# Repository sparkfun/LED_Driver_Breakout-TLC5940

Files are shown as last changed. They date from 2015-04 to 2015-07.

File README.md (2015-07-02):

SparkFun LED Driver Breakout -TLC5940
========================================

SparkFun LED Driver Breakout -TLC5940

[*SparkFun LED Driver Breakout -TLC5940(BOB-10616)*](https://www.sparkfun.com/products/10616)

 The TLC5940 is a 16 channel PWM unit with 12 bit duty cycle control (0-4095), 6 bit current limit control (0-63), and a daisy chainable serial interface. 
 This breakout board is a good way to take full advantage of this useful IC. 
 All 16 PWM channels are broken out to standard 0.1" headers, which run alongside convenient voltage and ground rails.

Repository Contents
-------------------

* **/Firmware** - Example code. 
* **/Hardware** - Eagle design files (.brd, .sch)
* **/Libraries** - Libraries for use with the TLC5940.
* **/Production** - Production panel files (.brd)

Documentation
--------------
* **[Library](https://github.com/sparkfun/SparkFun_TLC5940_Arduino_Library)** - Arduino Library for the TLC5940.
* **[SparkFun Fritzing repo](https://github.com/sparkfun/Fritzing_Parts)** - Fritzing diagrams for SparkFun products.
* **[SparkFun 3D Model repo](https://github.com/sparkfun/3D_Models)** - 3D models of SparkFun products. 

Version History
---------------

* [v1.3](https://github.com/sparkfun/LED_Driver_Breakout-TLC5940/tree/V_H1.3_L1.0.1) - Hardware version 1.3. Currently live. 
* [v1.2](https://github.com/sparkfun/LED_Driver_Breakout-TLC5940/tree/V_H.1_L1.0.1) - Hardware version 1.2

License Information
-------------------
This product is _**open source**_! 

The **hardware** is released under [Creative Commons ShareAlike 4.0 International](https://creativecommons.org/licenses/by-sa/4.0/).

Please use, reuse, and modify these files as you see fit. Please maintain attribution to SparkFun Electronics and release anything derivative under the same license.

Distributed as-is; no warranty is given.

- Your friends at SparkFun.

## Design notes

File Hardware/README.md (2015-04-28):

SparkFun <PRODUCT NAME> Design Files
=====================================

The .sch and .brd files hare are Eagle CAD schematic and PCB design files from SparkFun Electronics.
A freeware version of Eagle can be found [here](http://www.cadsoftusa.com/download-eagle/freeware/). 

License
---------
This product is open source! 
The hardware is released under [Creative Commons ShareAlike 4.0 International](https://creativecommons.org/licenses/by-sa/4.0/).

Please use, reuse, and modify these files as you see fit. Please maintain attribution to SparkFun Electronics and release anything derivative under the same license.

Distributed as-is; no warranty is given.

- Your friends at SparkFun.

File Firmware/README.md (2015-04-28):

SparkFun LED Driver Breakout - TLC5940 Firmware
==================================================

* **SparkFunHangingLEDArrayPongDemo* - Arduino Example. Used in this [hookup guide](https://learn.sparkfun.com/tutorials/interactive-hanging-led-array).

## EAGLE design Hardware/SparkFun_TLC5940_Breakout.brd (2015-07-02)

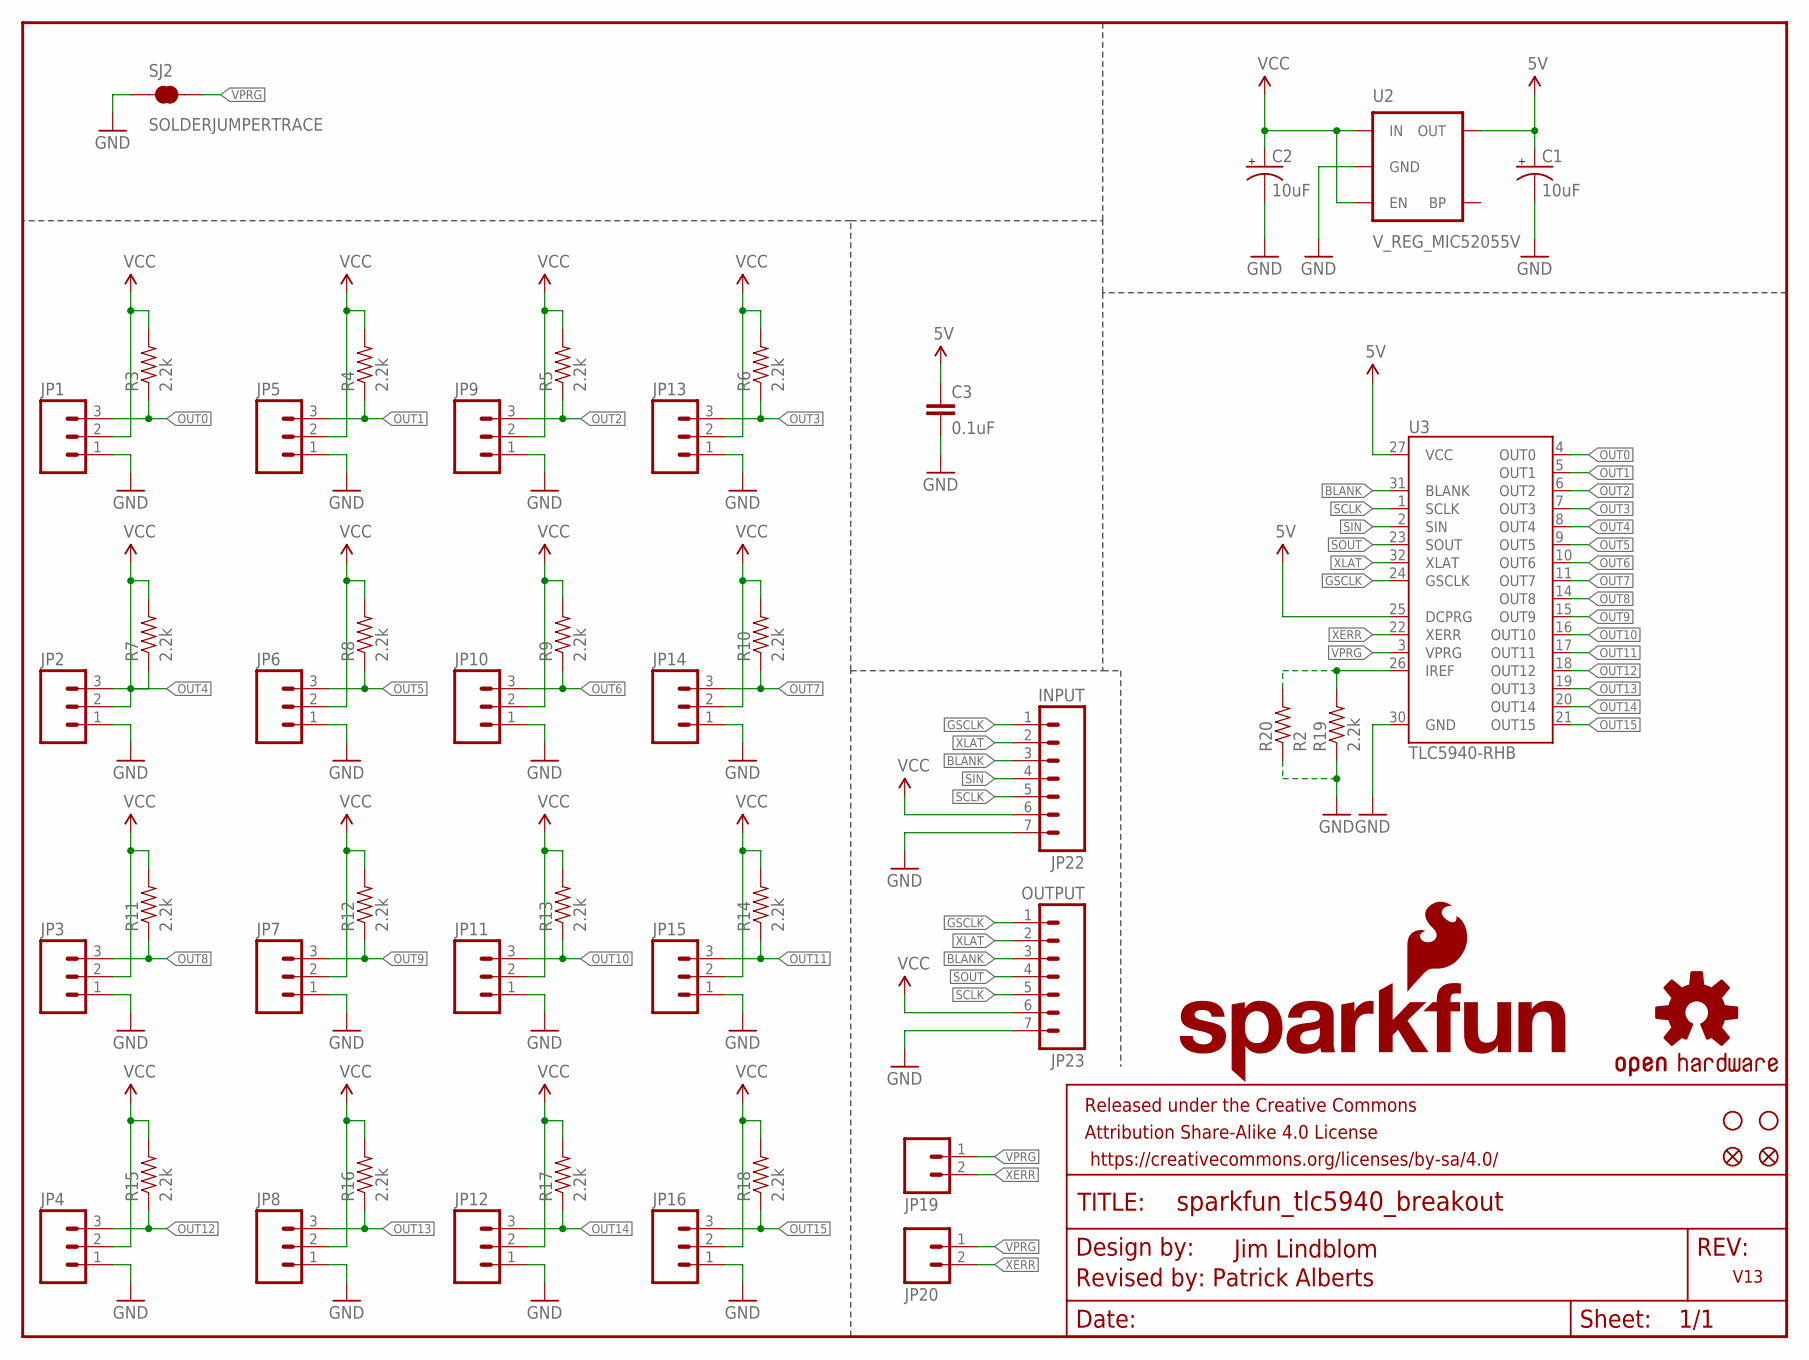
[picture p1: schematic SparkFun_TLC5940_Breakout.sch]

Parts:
C1: 10uF; EIA3216
C2: 10uF; EIA3528
C3: 0.1uF; 0603-CAP
FRAME1: FRAME-LETTER; CREATIVE_COMMONS
JP1, JP2, JP3, JP4, JP5, JP6, JP7, JP8, JP9, JP10, JP11, JP12, JP13, JP14, JP15, JP16: M03PTH; 1X03
JP17, JP18: STAND-OFF
JP19, JP20: M02PTH; 1X02
JP21, JP26: FIDUCIAL1X2; FIDUCIAL-1X2
JP22: INPUT; 1X07
JP23: OUTPUT; 1X07
LOGO1: OSHW-LOGOS; OSHW-LOGO-S
LOGO2: SFE_LOGO_NAME_FLAME.2_INCH; SFE_LOGO_NAME_FLAME_.2
R3, R4, R5, R6, R7, R8, R9, R10, R11, R12, R13, R14, R15, R16, R17, R18, R19: 2.2k; 0603-RES
R20: R2; AXIAL-0.3-KIT
SJ2: SOLDERJUMPERTRACE; SJ_2S-TRACE
U2: V_REG_MIC52055V; SOT23-5
U3: TLC5940-RHB; QFN-32

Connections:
5V: C1.A (+), C3.1, U2.5 (OUT), U3.25 (DCPRG), U3.27 (VCC)
BLANK: JP22.3, JP23.3, U3.31 (BLANK)
GND: C1.C (-), C2.C (-), C3.2, JP1.1, JP2.1, JP3.1, JP4.1, JP5.1, JP6.1, JP7.1, JP8.1, JP9.1, JP10.1, JP11.1, JP12.1, JP13.1, JP14.1, JP15.1, JP16.1, JP22.7, JP23.7, R19.1, R20.P$1 (1), SJ2.1, U2.2 (GND), U3.30 (GND)
GSCLK: JP22.1, JP23.1, U3.24 (GSCLK)
unnamed: R19.2, R20.P$2 (2), U3.26 (IREF)
OUT0: JP1.3, R3.1, U3.4 (OUT0)
OUT1: JP5.3, R4.1, U3.5 (OUT1)
OUT2: JP9.3, R5.1, U3.6 (OUT2)
OUT3: JP13.3, R6.1, U3.7 (OUT3)
OUT4: JP2.3, R7.1, U3.8 (OUT4)
OUT5: JP6.3, R8.1, U3.9 (OUT5)
OUT6: JP10.3, R9.1, U3.10 (OUT6)
OUT7: JP14.3, R10.1, U3.11 (OUT7)
OUT8: JP3.3, R11.1, U3.14 (OUT8)
OUT9: JP7.3, R12.1, U3.15 (OUT9)
OUT10: JP11.3, R13.1, U3.16 (OUT10)
OUT11: JP15.3, R14.1, U3.17 (OUT11)
OUT12: JP4.3, R15.1, U3.18 (OUT12)
OUT13: JP8.3, R16.1, U3.19 (OUT13)
OUT14: JP12.3, R17.1, U3.20 (OUT14)
OUT15: JP16.3, R18.1, U3.21 (OUT15)
SCLK: JP22.5, JP23.5, U3.1 (SCLK)
SIN: JP22.4, U3.2 (SIN)
SOUT: JP23.4, U3.23 (SOUT)
VCC: C2.A (+), JP1.2, JP2.2, JP3.2, JP4.2, JP5.2, JP6.2, JP7.2, JP8.2, JP9.2, JP10.2, JP11.2, JP12.2, JP13.2, JP14.2, JP15.2, JP16.2, JP22.6, JP23.6, R3.2, R4.2, R5.2, R6.2, R7.2, R8.2, R9.2, R10.2, R11.2, R12.2, R13.2, R14.2, R15.2, R16.2, R17.2, R18.2, U2.1 (IN), U2.3 (EN)
VPRG: JP19.1, JP20.1, SJ2.2, U3.3 (VPRG)
XERR: JP19.2, JP20.2, U3.22 (XERR)
XLAT: JP22.2, JP23.2, U3.32 (XLAT)

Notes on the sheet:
V13
Jim Lindblom
Revised by: Patrick Alberts

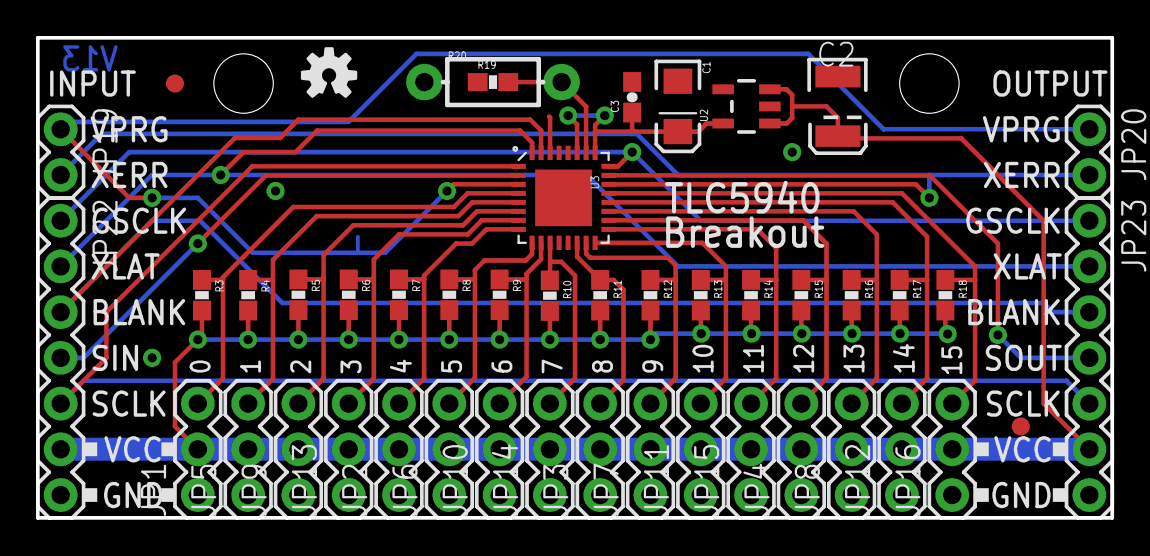
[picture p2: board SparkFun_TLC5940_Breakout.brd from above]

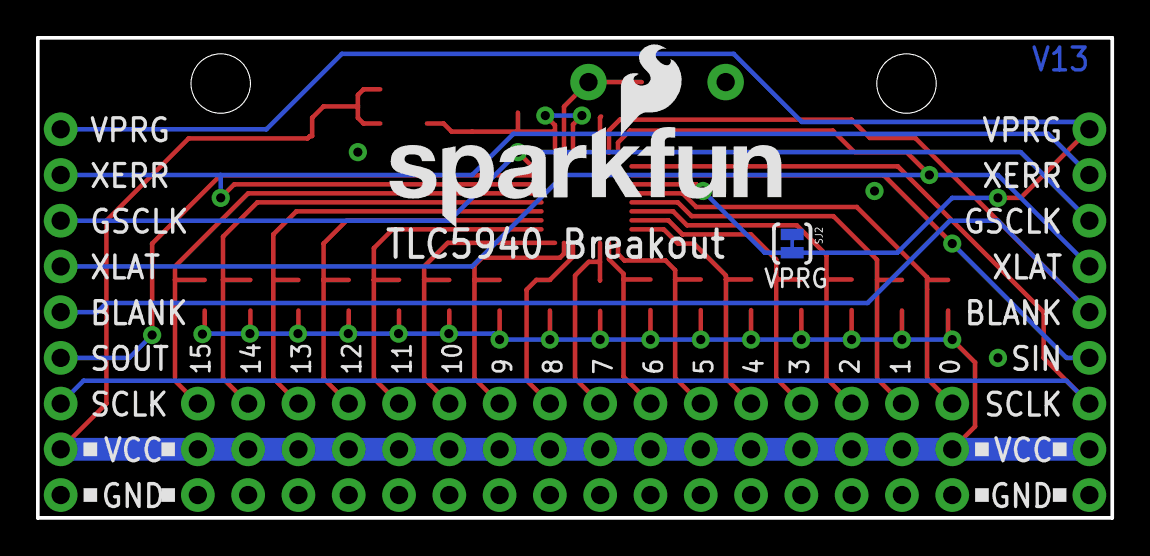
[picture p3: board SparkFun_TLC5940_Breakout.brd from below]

Board: 2 copper layers, 59.7 x 26.7 mm, 51 parts (2 on the bottom side), 28 nets.

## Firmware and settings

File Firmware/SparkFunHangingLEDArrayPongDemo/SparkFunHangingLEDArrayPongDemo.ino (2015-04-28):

#include "Tlc5940.h"

//LED Matrix Stuff

int pixel[12][6] = { //locations of LED channels in meatspace
  {56,64,44,35,15,11},
  {55,63,43,34,14,73},
  {54,62,42,33,13,9},
  {53,61,41,32,12,8},
  {60,72,40,31,23,7},
  {59,71,38,30,22,6},
  {58,70,37,29,21,5},
  {57,69,39,28,20,4},
  {52,68,48,27,19,3},
  {51,67,47,26,18,2},
  {50,66,46,25,17,1},
  {49,65,45,24,16,0}
};

int pixelstate[12][6] = { //LED PWM values
  {0,0,0,0,0,0},
  {0,0,0,0,0,0},
  {0,0,0,0,0,0},
  {0,0,0,0,0,0},
  {0,0,0,0,0,0},
  {0,0,0,0,0,0},
  {0,0,0,0,0,0},
  {0,0,0,0,0,0},
  {0,0,0,0,0,0},
  {0,0,0,0,0,0},
  {0,0,0,0,0,0},
  {0,0,0,0,0,0},
};

  int x;
  int y;
  
  
// Sensor Stuff  
  int lvldoor;
  int lvlwall;
  
// Pseudo-Radnom Stuff  
  int dice;

// Mode Stuff  
boolean modeflag = 0;

// Pong Stuff  
boolean xdir=0;
boolean ydir=0;
boolean movecycle=1;

// Spectrum Analyzer Stuff  
int Spectrum[7]; 
int spectrumReset=5;
int spectrumStrobe=6;
int spectrumAnalog=3;
int scaleFactor = 15;


void setup()
{
  
  Tlc.init();
  
  pinMode(spectrumReset, OUTPUT);
  pinMode(spectrumStrobe, OUTPUT);
  
    //Init spectrum analyzer
  digitalWrite(spectrumStrobe,LOW);
    delay(1);
  digitalWrite(spectrumReset,HIGH);
    delay(1);
  digitalWrite(spectrumStrobe,HIGH);
    delay(1);
  digitalWrite(spectrumStrobe,LOW);
    delay(1);
  digitalWrite(spectrumReset,LOW);
    delay(5);
    
    pinMode(A6, INPUT);
    pinMode(A7, INPUT);
    digitalWrite(A6, HIGH);    
    digitalWrite(A7, HIGH);    

}

void loop()
{
  
  //Mode Selecta
  if(digitalRead(A6)==LOW){modeflag=0;};
  if(digitalRead(A7)==LOW){modeflag=1;};
  
if(modeflag==0){
  readSpectrum();
  
for (int y=0; y<6; y++){
  for(int x=(Spectrum[y]/scaleFactor); x>=0; x--){
  Tlc.set(pixel[x][y], 4000);}};

Tlc.update();
delay(50);
Tlc.clear();}

if(modeflag==1){
  
    !movecycle;
    
//reach into meatspace  
  lvldoor = map(analogRead(A0), 40, 200, 2, 0);
  lvldoor = constrain(lvldoor,0,2);
  lvlwall = map(analogRead(A1), 30, 200, 2, 0);
  lvlwall = constrain(lvlwall,0,2);

//move the ball
if(movecycle){
  if(xdir==0 && x<10){x++;}
  if(xdir==1 && x>=1){x--;}
  if(xdir==0 && x==10){xdir=1;};
  if(xdir==1 && x==1){xdir=0;};

  if(ydir==0 && y<5){y++;}
  if(ydir==1 && y>=0){y--;}
  if(ydir==0 && y==5){ydir=1;};  
  if(ydir==1 && y==0){ydir=0;};}

//light the ball  
  pixelstate[x][y]=4000;

//check if lose  
  if(x==10 && lvldoor*2!=y && (lvldoor*2)+1!=y){
    loseCondition();
  }

//fade the field (tail on the ball)
  for (int y=0; y<6; y++){
  for(int x=1; x<11; x++){
  if(pixelstate[x][y]>0){
  pixelstate[x][y]=pixelstate[x][y]-1000;}
}
}

//ballfield update
for (int y=0; y<6; y++){
  for(int x=0; x<12; x++){
  Tlc.set(pixel[x][y], pixelstate[x][y]);}
};

//Paddles Cleanup
for(int i=0; i<6; i++){
 Tlc.set(pixel[0][i], 0);  
 Tlc.set(pixel[11][i], 0);  

}

//Paddles update
  Tlc.set(pixel[11][lvldoor*2], 4095);  Tlc.set(pixel[11][(lvldoor*2)+1], 4095);

  Tlc.update();

delay(250);
  
}
  
  
  
  
  
  
}

// Read 7 band equalizer.
void readSpectrum()
{
  // Band 0 = Lowest Frequencies.
  byte Band;
  for(Band=0;Band <7; Band++)
  {
    Spectrum[Band] = (analogRead(spectrumAnalog) + analogRead(spectrumAnalog) ) >>1; //Read twice and take the average by dividing by 2
    digitalWrite(spectrumStrobe,HIGH);
    digitalWrite(spectrumStrobe,LOW);     
  }
}

void loseCondition(){
   
  for (int iterate=0; iterate<50; iterate++){

    for (int channel = 0; channel < NUM_TLCS * 16; channel ++) {
    dice = random(0,50);
    Tlc.set(channel, dice*80);
    Tlc.update();
    }
delay(75);
    
}; 
  
}

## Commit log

2014-12-11 Initial Commit with BRD/SCH
    [TLC5940_Breakout-v13.brd, TLC5940_Breakout-v13.sch]
2015-01-14 computer change
    [TLC5940_Breakout-v13.brd, TLC5940_Breakout-v13.sch]
2015-01-29 Fixed sch issues, updated to 0603, minor re routes.
    [TLC5940_Breakout-v13.brd, TLC5940_Breakout-v13.sch]
2015-02-02 Fixed QC Checklist issues
    [TLC5940_Breakout-v13.brd, TLC5940_Breakout-v13.sch]
2015-04-28 Adding directories, necessary files
    [SparkFun_LED_Driver_Breakout-TLC5940.brd, SparkFun_LED_Driver_Breakout-TLC5940.sch]
2015-04-29 Squashed 'Libraries/Arduino/' content from commit 09ea0f2
    git-subtree-dir: Libraries/Arduino
    git-subtree-split: 09ea0f29b5f23ba79426c3c33b837437829adf9c
2015-06-08 Squashed 'Libraries/Arduino/' changes from 09ea0f2..9c3856a
    git-subtree-split: 9c3856a03f593f756db51a219c9790652309ccf4
    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
    [SparkFun_LED_Driver_Breakout-TLC5940.brd, SparkFun_LED_Driver_Breakout-TLC5940.sch]
2015-06-08 Squashed 'Libraries/Arduino/' changes from 9c3856a..7814504
    7814504 Fixing library.properties file
    09ea0f2 Updating README with associated product links
    b5160be Adding license, updating README
    71a8aa8 Adding library files
    fd5b4cd Fixing formatting
    2eb5d6c Updating README with Arduino library specific documentation
    c37f2aa Fixing structure more to be compliant with Arduino library requirements
    0cc7b09 Repo cleanup for ARduino library compatibility
    41c847d Swapping format to Arduino library compatibility
    6aa4859 Removed white space from file name
    7919005 Test for commit messages
    7c86b1b Updating directories for fritzing and 3D models
    1e95c7f Updating README formatting
    9d1bdf3 Merge pull reques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
    [SparkFun_LED_Driver_Breakout-TLC5940.brd, SparkFun_LED_Driver_Breakout-TLC5940.sch]
2015-10-05 Squashed 'Libraries/Arduino/' changes from 7814504..7c3d8c7
    7c3d8c7 Fixing compilation error
    84f472c Fixing library.properties to enable loading in Arduino IDE
    git-subtree-split: 7c3d8c7861b762511ad4b3e899ffde8689cd396d
    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
2016-01-11 Squashed 'Libraries/Arduino/' changes from 7c3d8c7..18a0c0f
    18a0c0f Updating file names for codebender fix
    git-subtree-split: 18a0c0fa8911f19f615ccea7981273a6ffd0adf4
    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

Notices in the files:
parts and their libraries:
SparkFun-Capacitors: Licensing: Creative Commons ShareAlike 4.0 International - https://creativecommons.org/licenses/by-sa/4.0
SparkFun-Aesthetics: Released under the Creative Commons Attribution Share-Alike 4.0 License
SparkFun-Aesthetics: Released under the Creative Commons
